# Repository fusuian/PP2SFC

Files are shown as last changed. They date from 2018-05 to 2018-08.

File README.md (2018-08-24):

# Precision Pro to SFC Adapter

マイクロソフト製フライトスティック SideWinder Precision Pro を、任天堂スーパーファミコン（およびファミリーコンピュータ）に接続するアダプタです。
PWM出力を使って、アナログスティックの傾きを移動量に反映させています。

## ハードウェア

アダプタ本体となるマイコンボードと電子部品をブレッドボードに組み付けます。
ブレッドボードの配線図は、PP2SFC_BreadBoard.pdfをご覧ください。

 - ブレッドボード ハーフサイズ x 2 (または中央で絶縁されたフルサイズ x 1)
 - マイコンボード Arduino Nano
 - シフトレジスタIC TC4021BP x 2
 - カーボン抵抗 56kΩ x 16
 - ダイオード 1N4007 x 1
 - ジャンパワイヤ 適宜

 - Dサブ15ピン メスコネクタ (to Precision Pro)
 − ゲーム機接続ケーブル (以下の3種のうち、手持ちのゲーム機に合わせて)
    - Dサブ9ピン オスコネクタ (to FC compatible)
    - ファミコンコントローラ オスコネクタ
    - ニューファミコンコントローラ オスコネクタ
    - スーパーファミコンコントローラ オスコネクタ
 - USBバッテリ (アダプタ電源)

## ソフトウェア

Arduino IDEを使用して、PP2SFC スケッチをArduino Nanoに書き込みます。

 - PP2SFC.ino 	スケッチ本体
 - PrecisionPro.h	PrecisionProクラス
 - portmacro.h	 digitalWrite に相当する、portOn/portOffマクロを定義

## 使用方法

アダプタボードに Precision Proとゲーム機を接続したら、
USBバッテリをArduino Nanoに接続して、ゲーム機に電源を入れます。

起動直後はファミコン配列、スティック上下反転、連射なしのモードになります。

### ファミコン配列

電源を入れた直後はこのモードになります。
ファミコンソフト『スターラスター』（ナムコ）向けの設定です。

 - スティック 十字キー（疑似アナログ・反転モードあり）
 - ラダー（スティックひねり）	なし
 - スロットル	なし

 - Fireボタン			Bボタン
 - Topボタン			Aボタン
 - Top Upボタン		SELECTボタン
 - Top Downボタン		STARTボタン
 - HATスイッチ		十字キー（反転モードなし）

 - Aボタン	Aボタン
 - Bボタン	Bボタン
 - Cボタン	SELECTボタン
 - Dボタン	STARTボタン

#### モード切り替えボタン

Shiftボタンと特定のボタンを同時に押すと、いつでもモード変更ができます。

 - Shift + Topボタン		ファミコン配列／スーパーファミコン配列の切り替え
 - Shift + Fireボタン	 	Fireボタンの連射のオン・オフ
 - Shift + HATスイッチ上	スティックの上下を十字キーの上下に割り当てる
 - Shift + HATスイッチ下	スティックの上下を十字キーの下上に割り当てる

### スーパーファミコン配列

スーパーファミコンソフト『スターフォックス』（任天堂）向けの設定です。
スティックの根元のスロットルにX（ブレーキ）とY（ブースト）を割り当てていますが、L/Rボタンを二度押すローリングは出しにくいです。

 - スティック 十字キー（疑似アナログ）
 - ラダー（スティックひねり）左	Lボタン
 - ラダー（スティックひねり）右	Rボタン
 - スロットル上	Xボタン
 - スロットル中	なし
 - スロットル下	Yボタン

 - Fireボタン		Bボタン
 - Topボタン			Aボタン
 - Top Upボタン		Xボタン
 - Top Downボタン		Yボタン
 - Shift + Top Upボタン		SELECTボタン
 - Shift + Top Downボタン	 	STARTボタン
 - HATスイッチ	十字キー（反転モードなし）

 - Aボタン	Aボタン
 - Bボタン	Bボタン
 - Cボタン	Xボタン
 - Dボタン	Yボタン

## 参考ウェブサイト

1. [MaZderMind/SidewinderInterface](https://github.com/MaZderMind/SidewinderInterface/tree/master/software) Precision Proの通信プロトコルについて、オシロスコープ画像つきで詳細に説明されています。また、union sw_data_t の定義を引用しています。
2. [SFCコントローラーをパラレル風の信号に変換](http://d-tomo.net/pic2.html) スーファミコントローラの通信プロトコルについて、詳細に説明されています。
3. [SNESkey Arcade Interface](http://arcadecontrols.com/arcade_sneskey.html)4021を二つ使った、スーファミコントローラの回路図が紹介されています。
4. [Arduino SPI マスターとスレーブでデータ通信](https://ogapsan.com/archives/343) ArduinoをSPIスレーブとして動作させるソースコードが紹介されています。

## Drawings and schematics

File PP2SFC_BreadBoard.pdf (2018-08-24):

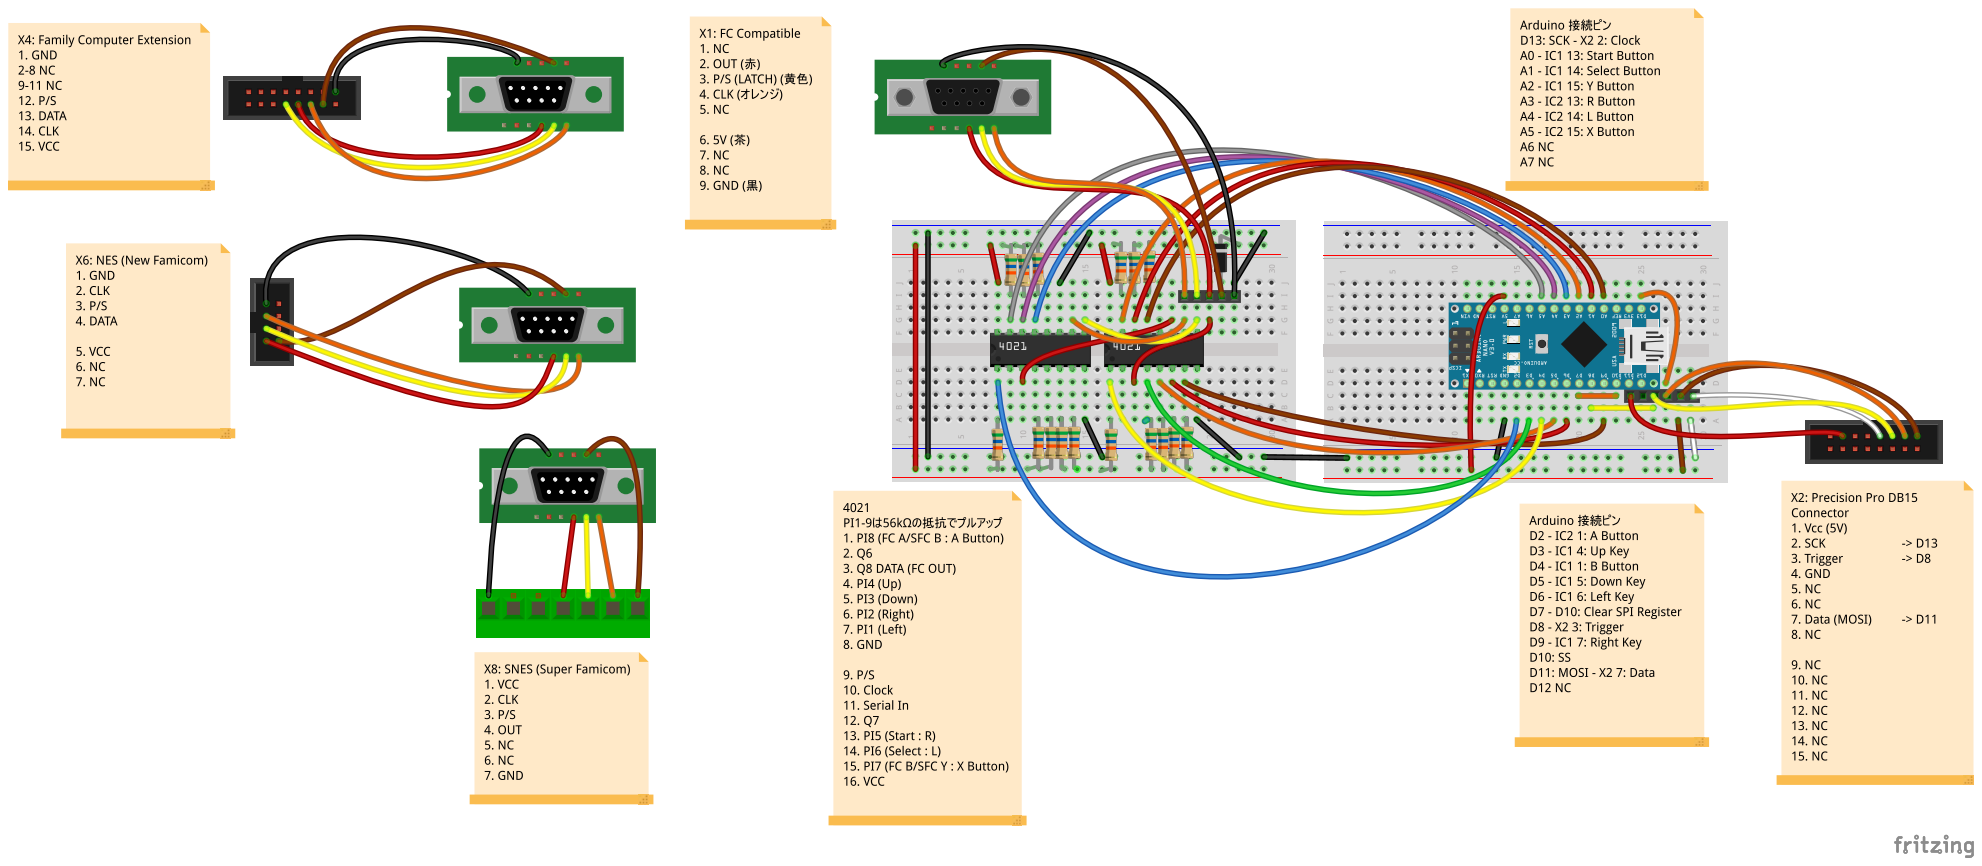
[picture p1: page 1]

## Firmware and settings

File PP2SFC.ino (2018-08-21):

/**
 * Sidewinder Precision Pro Adapter for Star Fox
 *
 * MS製フライトスティック Sidewinder Precision Pro をスーパーファミコンに
 * 接続して、スターフォックスを遊ぶアダプタ。
 *
 * コントロールモードAに対応
 * ローリング（LまたはRの連打による回転）は未対応
 *
 */

#include "PrecisionPro.h"
#include "portmacro.h"

#define PIN_TRIGGER 8 // Precision Proのトリガーとつなぐデジタルピン
#define PIN_CLEAR   7 // Precision Proとの通信開始（レジスタクリア）のデジタルピン

bool mode_rapid_fire = false; // fireキー連射モード
bool mode_reverse = true;     // 上下反転モード
bool mode_super = false;      // スーパーファミコンモード(トップアップ/ダウンキーがXYボタンになり、スティックのひねりがLRボタンになる)

// X/Y軸のしきい値
const int threshold = 16;


PrecisionPro * pp;

// SPI割り込み
ISR (SPI_STC_vect)
{
  pp->add_buf(SPDR);
}


// キー/ボタンに対応するデジタルピン

// 上下左右はPWM対応のピンであること（疑似アナログジョイスティック）
const int up_pin    = 3;
const int down_pin  = 5;
const int left_pin  = 6;
const int right_pin = 9;

const int sfc_a_pin = 2;
const int sfc_b_pin = 4;



const int start_pin  = A0;
const int select_pin = A1;
const int sfc_y_pin  = A2;
const int sfc_r_pin  = A3;
const int sfc_l_pin  = A4;
const int sfc_x_pin  = A5;

const int fc_a_pin = sfc_b_pin;
const int fc_b_pin = sfc_y_pin;

// mode_superに応じて、スティック頭のボタンの番号を保持
int fire_pin;
int top_pin;
int top_up_pin;
int top_down_pin;

// mode_reverseに応じて、Y軸のピン番号を保持
int p_down, p_up;             

int rapid_counter = 1;        // 連射間隔を制御するカウンタ
const int rapid_interval = 6; // 連射間隔

unsigned int cnt = 0;

// ファミコン/スーファミによって、操縦桿の頭のファイア/トップ/
// トップアップ/トップダウンボタンの割り振りを変更する
void set_super(bool state)
{
  mode_super = state;
  if (state) {
    // スーファミの場合 Y/A/X/B
    // セレクト/スタートは、シフトキー + トップアップ/ダウン
    fire_pin = sfc_y_pin;
    top_pin = sfc_a_pin;
    top_up_pin = sfc_x_pin;
    top_down_pin = sfc_b_pin;
  } else {
    // ファミコンの場合 B/A/Select/Start
    fire_pin = fc_b_pin;
    top_pin = fc_a_pin;
    top_up_pin = select_pin;
    top_down_pin = start_pin;
  }
}

// 操縦桿の上下反転モードを設定する
void set_reverse(bool state)
{
  mode_reverse = state;
  if (state) {
    p_up = down_pin;
    p_down = up_pin;
  } else {
    p_up = up_pin;
    p_down = down_pin;
  }
}



void setup (void)
{
  Serial.begin(57600);   // debugging

  pinMode(up_pin, OUTPUT);
  pinMode(down_pin, OUTPUT);
  pinMode(left_pin, OUTPUT);
  pinMode(right_pin, OUTPUT);

  pinMode(select_pin, OUTPUT);
  pinMode(start_pin, OUTPUT);

  pinMode(sfc_a_pin, OUTPUT);
  pinMode(sfc_b_pin, OUTPUT);
  pinMode(sfc_x_pin, OUTPUT);
  pinMode(sfc_y_pin, OUTPUT);
  pinMode(sfc_l_pin, OUTPUT);
  pinMode(sfc_r_pin, OUTPUT);

  portOn(up_pin);
  portOn(down_pin);
  portOn(left_pin);
  portOn(right_pin);
  portOn(select_pin);
  portOn(start_pin);

  portOn(sfc_a_pin);
  portOn(sfc_b_pin);
  portOn(sfc_x_pin);
  portOn(sfc_y_pin);
  portOn(sfc_l_pin);
  portOn(sfc_r_pin);

  pp = new PrecisionPro(PIN_TRIGGER, PIN_CLEAR);
  pp->init();
  set_super(mode_super);
  set_reverse(mode_reverse);
}



void print_status()
{
  int x = pp->x();
  int y = pp->y();
  char * buf = pp->data().buf;

  Serial.print(++cnt);
  Serial.print(": ");
  for (int i=0; i < 6; i++){
      unsigned char b = buf[i];
      if (b < 16) {
        Serial.print("0");
      }
      Serial.print(b, HEX);
      Serial.print(":");
  }

  Serial.print(" (");
  Serial.print(x);
  Serial.print(", ");
  Serial.print(y);
  Serial.print(")");

  Serial.print("  top: ");
  Serial.print(pp->fire());
  Serial.print(pp->top());
  Serial.print(pp->top_up());
  Serial.print(pp->top_down());

  Serial.print(": base: ");
  Serial.print(pp->a());
  Serial.print(pp->b());
  Serial.print(pp->c());
  Serial.print(pp->d());

  Serial.print("; ");
  Serial.print(pp->shift());

  Serial.print("; thr: ");
  Serial.print(pp->throttle());
  Serial.print("; rud:");
  Serial.print(pp->rudder());
  Serial.print("; hat:");
  Serial.print(pp->hat_switch());
  Serial.println();
}


char pf, pt;

void do_shift()
{
  if (mode_super) {
    // shift+top_up/top_down → SELECT, START
    if (pp->top_up()) {
      portOff(select_pin);
    } else {
      portOn(select_pin);
    }

    if (pp->top_down()) {
      portOff(start_pin);
    } else {
      portOn(start_pin);
    }
  }

  // shift+ファイアボタンで連射のオン・オフを切り替え
  int f = pp->fire();
  if (f && pf == 0) {
    mode_rapid_fire = !mode_rapid_fire;
  }
  pf = f;

  // shift+トップボタンでスーファミモードを切り替え
  int t = pp->top();
  if (t && pt == 0) {
    set_super(!mode_super);
  }
  pt = t;

  // shift+HATスイッチの上下で操縦桿の上下を反転
  switch (pp->hat_switch()) {
  case 1:
    set_reverse(false);
    break;
  case 5:
    set_reverse(true);
    break;
  default:
    break;
  }
}



bool do_hat_switch()
{
    switch (pp->hat_switch()) {
    case 0:
        return false;

    case 1:
        analogWrite(up_pin, 0);
        analogWrite(down_pin, 255);
        analogWrite(left_pin, 255);
        analogWrite(right_pin, 255);
        break;
    case 2:
        analogWrite(up_pin, 0);
        analogWrite(down_pin, 255);
        analogWrite(left_pin, 255);
        analogWrite(right_pin, 0);
        break;

    case 3:
        analogWrite(up_pin, 255);
        analogWrite(down_pin, 255);
        analogWrite(left_pin, 255);
        analogWrite(right_pin, 0);
        break;

    case 4:
        analogWrite(up_pin, 255);
        analogWrite(left_pin, 255);
        analogWrite(down_pin, 0);
        analogWrite(right_pin, 0);
        break;

    case 5:
        analogWrite(up_pin, 255);
        analogWrite(left_pin, 255);
        analogWrite(right_pin, 255);
        analogWrite(down_pin, 0);
        break;

    case 6:
        analogWrite(up_pin, 255);
        analogWrite(right_pin, 255);
        analogWrite(down_pin, 0);
        analogWrite(left_pin, 0);
        break;

    case 7:
        analogWrite(up_pin, 255);
        analogWrite(down_pin, 255);
        analogWrite(right_pin, 255);
        analogWrite(left_pin, 0);
        break;

    case 8:
        analogWrite(up_pin, 0);
        analogWrite(left_pin, 0);
        analogWrite(down_pin, 255);
        analogWrite(right_pin, 255);
        break;

    default:
        Serial.print("hat switch error: ");
        Serial.println(pp->hat_switch());
        break;
    }
    return true;
}


bool do_stick_xy()
{
  int y = pp->y() / 2;
  if (y > threshold) {
    analogWrite(p_down, 255-y);
  } else {
    analogWrite(p_down, 255);
  }

  if (y < -threshold) {
    analogWrite(p_up, 256+y);
  } else {
    analogWrite(p_up, 255);
  }

  int x = pp->x() / 2;
  if (x > threshold) {
    analogWrite(right_pin, 255-x);
  } else {
    analogWrite(right_pin, 255);
  }
  if (x < -threshold) {
    analogWrite(left_pin, 256+x);
  } else {
    analogWrite(left_pin, 255);
  }
  return true;
}


void do_buttons()
{
  // ファイアボタン
  if (mode_rapid_fire) {
    if (pp->fire()) {
      // 連射
      if (--rapid_counter == 0) {
        portOff(fire_pin);
        rapid_counter = rapid_interval;
      } else {
        portOn(fire_pin);
      }
    } else if (pp->b()) {
      portOff(fire_pin);
      rapid_counter = 1;
    } else {
      portOn(fire_pin);
      rapid_counter = 1;
    }
  } else {
    // 連射なし
    if (pp->fire() || pp->b()) {
      portOff(fire_pin);
    } else {
      portOn(fire_pin);
    }
  }

  // トップボタン
  if (pp->top() || pp->a()) {
    portOff(top_pin);
  } else {
    portOn(top_pin);
  }

  bool non_top_up = true;
  bool non_top_down = true;

  // トップ上ボタン
  if (pp->top_up() || pp->c()) {
    portOff(top_up_pin);
    non_top_up = false;
  } else {
    portOn(top_up_pin);
  }

  // トップ下ボタン
  if (pp->top_down() || pp->d()) {
    portOff(top_down_pin);
    non_top_down = false;
  } else {
    portOn(top_down_pin);
  }

  if (mode_super) {
  // スロットル→X,Bボタン（for STARFOX）
    if (non_top_down) {
      if (pp->throttle() < 16) {
        portOff(sfc_b_pin);
      } else {
        portOn(sfc_b_pin);
      }
    }

    if (non_top_up) {
      if (pp->throttle() > 104) {
        portOff(sfc_x_pin);
      } else {
        portOn(sfc_x_pin);
      }
    }

    // ツイスト→LR
    if (pp->rudder() <= -32) {
      portOff(sfc_l_pin);
    } else {
      portOn(sfc_l_pin);
    }

    if (pp->rudder() >= 20) {
      portOff(sfc_r_pin);
    } else {
      portOn(sfc_r_pin);
    }

//  } else {
//    // スロットル→Aボタン（for STARLUSTER）
//    if (pp->m() < 16) {
//      analogWrite(top_pin, pp->m()*2);
//    }
  }
}


void loop (void)
{
  pp->update();
  delayMicroseconds(1000); // ここで待機する間に割り込みでSPI受信

  print_status();

  if (pp->shift()) {
    do_shift();
  } else {
    // HATスイッチの操作が操縦桿より優先（for Star Luster）
    if (do_hat_switch() == false) {
      do_stick_xy();
    }
    do_buttons();
  }
  delay(15);
}

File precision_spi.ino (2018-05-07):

#include "PrecisionPro.h"

#define PIN_TRIGGER 3 // Game port 3
#define PIN_CLEAR   6 

PrecisionPro * pp;

// SPI割り込み
ISR (SPI_STC_vect)
{
  pp->add_buf(SPDR);
}


void setup (void)
{
  Serial.begin (115200);   // debugging

  pp = new PrecisionPro(MOSI, SCK, SS, PIN_TRIGGER, PIN_CLEAR);
}


void loop (void)
{
  pp->update();
  delayMicroseconds(1000); // ここで待機する間に割り込みでSPI受信

  volatile sw_data_t & sw_data = pp->data();
  for (int i=0; i < 6; i++){  
      Serial.print(sw_data.buf[i], HEX);
      Serial.print(":");
  }
  Serial.println("");

    Serial.print("sw_data: ");
    Serial.print(sw_data.btn_fire);
    Serial.print("; ");
    Serial.print(sw_data.btn_top);
    Serial.print("; ");
    Serial.print(sw_data.btn_top_up);
    Serial.print("; ");
    Serial.print(sw_data.btn_top_down);
    Serial.print("; x=");
    Serial.print(sw_data.x - 512);
    Serial.print("; y=");
    Serial.print(sw_data.y - 512);
    Serial.print("; r=");
    Serial.print(sw_data.r - 32);
    Serial.print("; m=");
    Serial.print(sw_data.m);
    Serial.println();

  delay(50);
}

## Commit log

2017-10-07 Precision Proの信号をSPIで受信、シリアルコンソールに値を表示
2017-10-07 LSBFIRSTの設定でsw_data_t型で解釈成功
2017-10-09 PrecisionPro.hを分割、クラス化
2018-05-07 ISRをino側に移動
2018-05-07 sw_dataとposをPrecisionProクラスのメンバに移動、data()やスティック情報読み取りメソッドを追加。
2018-05-14 リネーム
2018-05-14 ボタンチェック関数がboolを返すよう変更
2018-05-14 ファミコンアダプタ
2018-05-14 a,b,c,dボタンの判別関数を追加
2018-05-14 fireボタンを連射に、a,bボタンを認識、c,dボタンをselect,startに。
2018-05-14 ブレッドボード配線図を追加
    [precision_spi_fc.fzz]
2018-05-19 上下左右にPWM出力で、疑似アナログスティック動作を実装。
2018-05-20 headキーに対応
2018-05-20 shiftキーの長押しでSELECT、普通押しでSTART。
2018-05-20 fire/top/top_up/top_down_pinにファミコンまたはスーファミのピンを割り当て。
2018-05-20 デジタルピンの初期化にfor文を使用
2018-05-27 スーパーファミコン（スターフォックス）対応、コメント追加
2018-05-28 配線を修正
    [precision_spi_fc.fzz]
2018-05-28 スーパーファミコン版配線図を作成
    [precision_spi_sfc.fzz]
2018-06-10 リセットしたあと、数秒間特定のボタンを押し続けることで動作モードを変更
2018-06-10 デバッグ出力を抑制
2018-06-10 コメント追加
2018-06-10 結線図を修正
    [precision_spi_sfc.fzz]
2018-08-12 portmacro.hで、ピンごとのポートの割り振りを自動判定
2018-08-12 出力ピンの割当を変更
2018-08-12 シリアルメッセージの変更
2018-08-12 print_status()を分割
2018-08-12 ポート番号の判定ミスを修正
2018-08-12 initialize()によるリセット時の各モード切替をやめ、動作中シフトキーと特定キーの組み合わせでモード変更
2018-08-12 PrecisionProクラスにportmacro.hを適用し、クリアピンとトリガーピンのピン制限（D2～D7ピンしか使えなかった）をなくす
2018-08-16 コメント整理
2018-08-20 arrow_key()からhat_switch()を分割、排他処理とする
2018-08-20 デジタルピンの配列を変更。Precision Proコネクタのプルアップ抵抗を内蔵プルアップ抵抗に置き換える。
    [precision_spi_sfc.fzz]
2018-08-20 PrecisionProのコンストラクタから、ピンの設定部分をinit()に分割
2018-08-20 mode系変数の初期値がデフォルト値として機能するよう修正
2018-08-20 コメントの修正
2018-08-20 threshold値を調整
2018-08-20 PrecisionProの大文字のプライベート変数をリネーム、コンストラクタのデフォルト引数を追加。
2018-08-20 PrecisionProクラスのhead(), m(), r()をhat_switch(), throttle(), rudder()にリネーム
2018-08-20 a_pin, b_pin を fc_a_pin, fc_b_pin にリネーム
2018-08-20 コメントを追加して不要な行を削除
2018-08-21 使っていない変数を削除
2018-08-21 shift(), hat_switch(), arrow_key(), buttons()をリネーム
2018-08-21 ソースの見栄えを調整
2018-08-24 PP2SFCにリネーム
    [PP2SFC.fzz, precision_spi_sfc.fzz]
2018-08-24 README.mdを追加
2018-08-24 配線図を修正
    [PP2SFC.fzz]
2018-08-24 古い配線図を削除
2018-09-23 portmacro.hを更新（isPortのバグを取りisPinにリネーム)
